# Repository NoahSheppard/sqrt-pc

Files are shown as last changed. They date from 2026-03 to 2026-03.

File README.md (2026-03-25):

## **UNDER CONSTRUCTION**

# Sqrt(PC)
A mini PC helper with a battery, and a microcontroller powerful enough to run programs itself...

For now this repo will be kept simple, with just the bare essentials in it. If you want a more in-depth guide into my inner thought process and how things came together over time, and feel that the commit history is weak, please find the Blueprint link [here](https://blueprint.hackclub.com/projects/13283)

# Bill Of Materials
<!-- BOM_START -->
| Reference | Qty | Value | Footprint | Price ($AUD unless marked) | Purchase-URL | Label | Notes |
| --- | --- | --- | --- | --- | --- | --- | --- |
| C46 | 1 | 100nF | C315C104K5R5TA:CAPRR254W54L381T254H466B | $0.70 | https://au.mouser.com/ProductDetail/KEMET/C315C104K5R5TA?qs=AHmto%252BvZ7OG2Mx7li%2Fn8YQ%3D%3D | Power Circuit - 100nF Capacitor |  |
| D1 | D2 | D3 | D5 | D6 | D7 | 6 | ~ | ScottoKeebs_Components:Diode_DO-35 | $- | N/A | Diodes for the Keyswitch array |  |
| D4 | 1 | LED_ARBG | LED_SMD:LED_Kingbright_AAA3528ESGCT | $0.74 | https://au.mouser.com/ProductDetail/Kingbright/AAA3528ESGCT?qs=HXFqYaX1Q2ztii0bK20PQg%3D%3D | LED for battery status |  |
| D9 | D10 | D11 | D12 | D13 | D14 | 6 | LED_SK6812MINI | ScottoKeebs_Components:LED_SK6812MINI | $- | N/A | RGB LEDs |  |
| DS1 | 1 | 4311 | 4311:MODULE_4311 | $9.37 | https://www.aliexpress.com/item/1005009447193931.html | Screen |  |
| J1 | 1 | Conn_01x02 | Connector_Molex:Molex_PicoBlade_53048-0210_1x02_P1.25mm_Horizontal | $3.76 | https://www.aliexpress.com/item/32807183020.html | Battery Connector | Can only get 50 min |
| Q1 | 1 | AO3401A | Package_TO_SOT_SMD:SOT-23W_Handsoldering | $0.97 | https://www.aliexpress.com/item/1005008934110148.html | Power Circuit - P-Channel MOSFET - Power Latch | Can only get 10 min |
| R2 | 1 | FMP100JR-52-2K2 | KiCADv6:FMP100JR_52_2K2 | $0.19 | https://au.mouser.com/ProductDetail/YAGEO/FMP100JR-52-2K2?qs=wcZjbqjoJegNfVYDP1qQwg%3D%3D | Power Circuit - 2.2kOhm Resistor |  |
| R3 | R4 | 2 | MFR-25FBF52-1K | MFR-25FBF52-1K:RESAD1100W55L680D260 | $0.31 | https://au.mouser.com/ProductDetail/YAGEO/MFR-25FTF52-1K47?qs=gt1LBUVyoHl4e3xmkemLyA%3D%3D | Power Circuit - 1.47 kOhms Resistor |  |
| R5 | R6 | 2 | RNC55H1002FMRE7 | RNC55H1002FMRE7:RESAD1081W64L635D269 | $0.85 | https://www.jaycar.com.au/10k-ohm-0-5-watt-metal-film-resistors-pack-of-8/p/RR0596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 | Power Circuit - 10kOhm Resistor | Can only get in a 8 pack for this cheap |
| RN1 | 1 | CAY16-1003F4LF | CAY16-1003F4LF:RESCAF80P320X160X60-8N | $0.15 | https://au.mouser.com/ProductDetail/Bourns/CAY16-1003F4LF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 | Power Circuit - 4 100kOhm Resistors |  |
| S1 | S2 | S3 | S5 | S6 | S7 | 6 | ~ | Button_Switch_Keyboard:SW_Cherry_MX_1.00u_PCB | $- | N/A | Keyswitches | I own these already |
| S8 | 1 | PTS526_SMG15_SMTR2_LFS | PTS526_SMG15_SMTR2_LFS:SW_PTS526_SMG15_SMTR2_LFS | $0.24 | https://au.mouser.com/ProductDetail/CK/PTS526SMG15SMTR2-LFS?qs=Imq1NPwxi76tu1Vo5JUXUg%3D%3D | Power Button |  |
| U1 | 1 | WEMOSC3mini | RF_Module:WEMOS_C3_mini | $8.94 | https://www.aliexpress.com/item/1005004740051202.html | Microcontroller | Does not come with pin headers |
| U2 | 1 | TP4056-42-ESOP8 | Package_SO:SOIC-8-1EP_3.9x4.9mm_P1.27mm_EP2.41x3.3mm | $1.44 | https://www.lcsc.com/product-detail/C16581.html | Power Circuit - IC | Price in AUD | purchased in USD - rough conversion rate |
|  | 2 |  |  | $0.35 | https://core-electronics.com.au/header-male-pin-01x20.html | Microcontroller Pin Headers | Not in KiCad |
|  |  |  |  |  |  |  |  |
| Total Price | $28.01 |  |  |  |  |  |  |
|  |  |  |  |  |  |  |  |
<!-- BOM_END -->

# Schematic
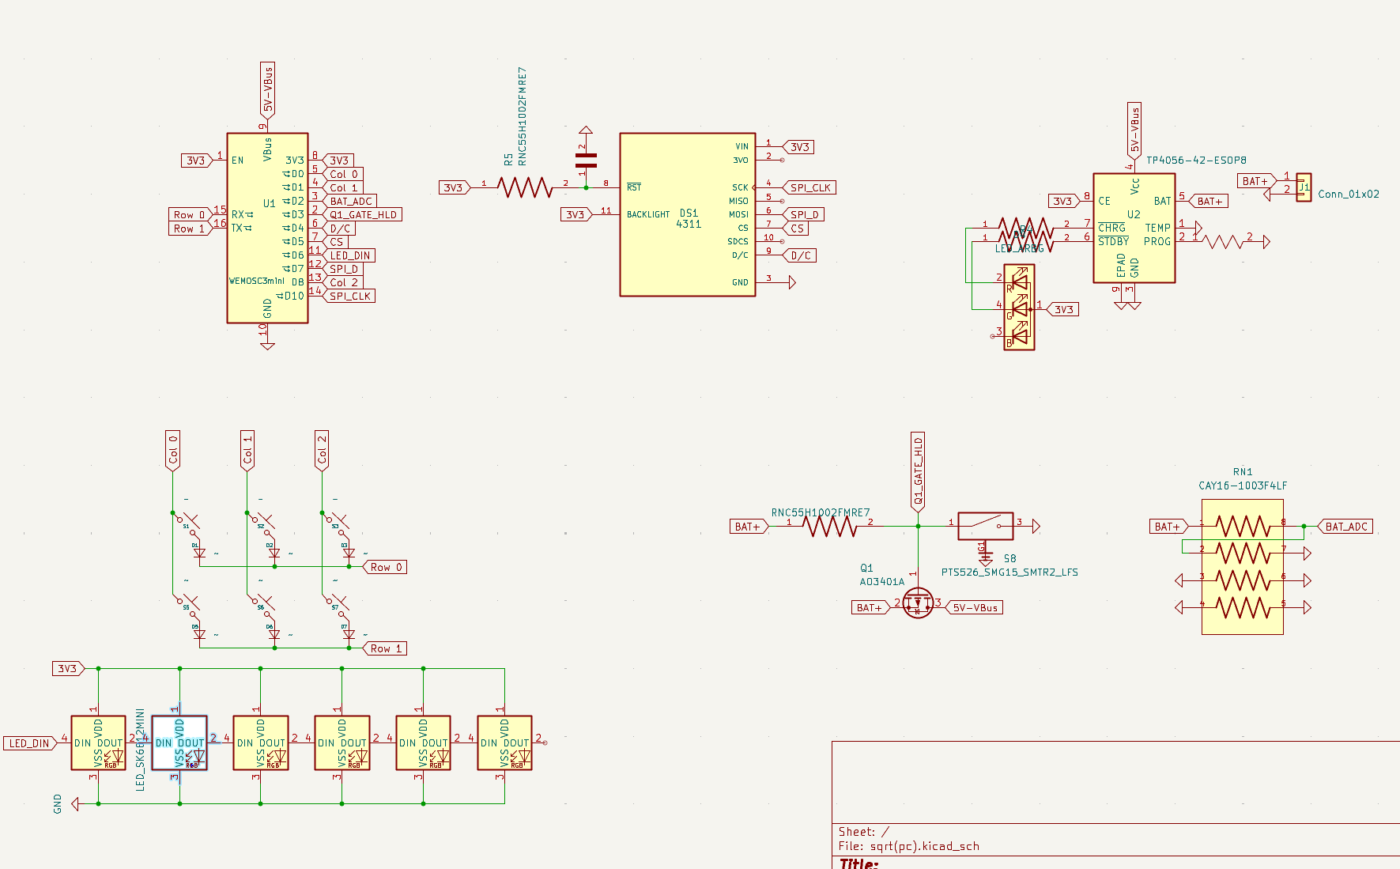
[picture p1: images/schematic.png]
Schematic


# PCB
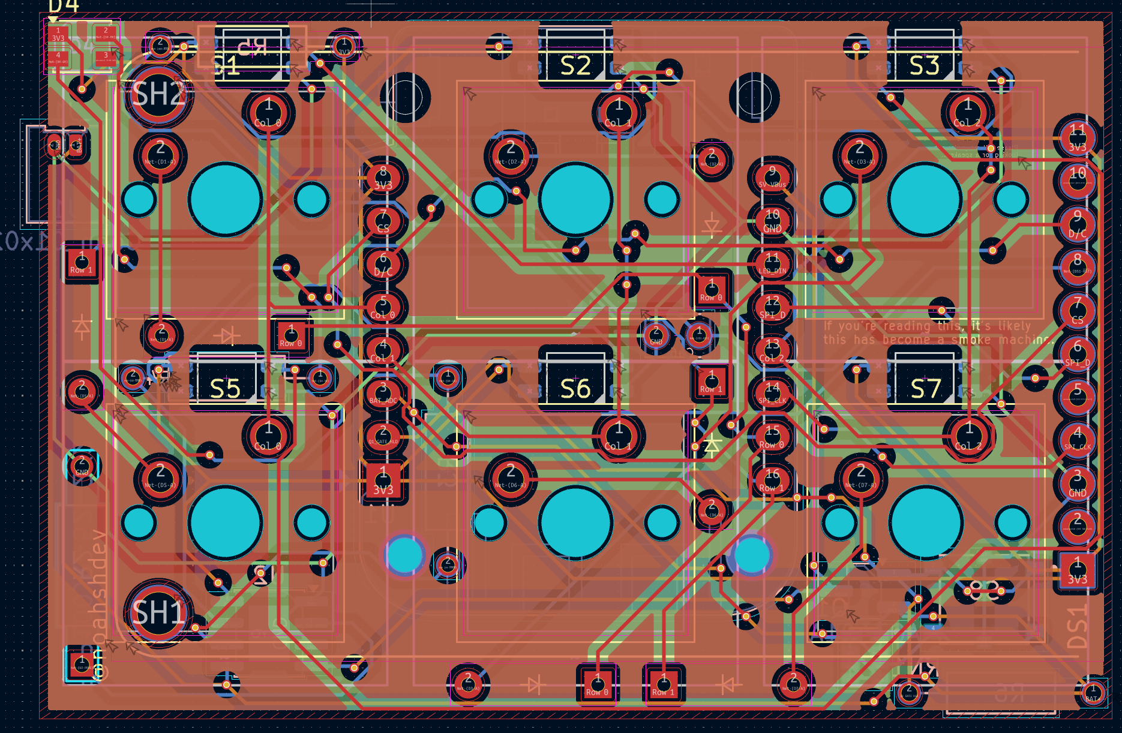
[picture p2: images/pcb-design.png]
PCB Design

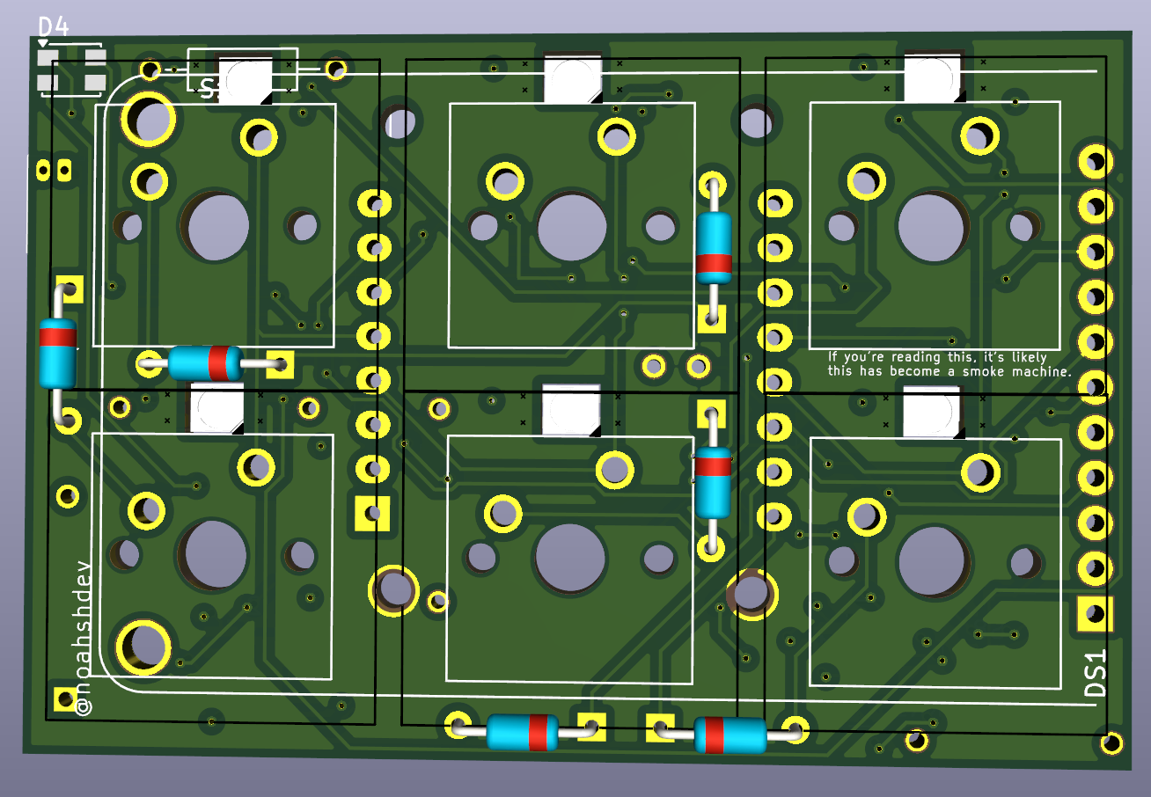
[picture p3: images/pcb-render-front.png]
PCB Render Front

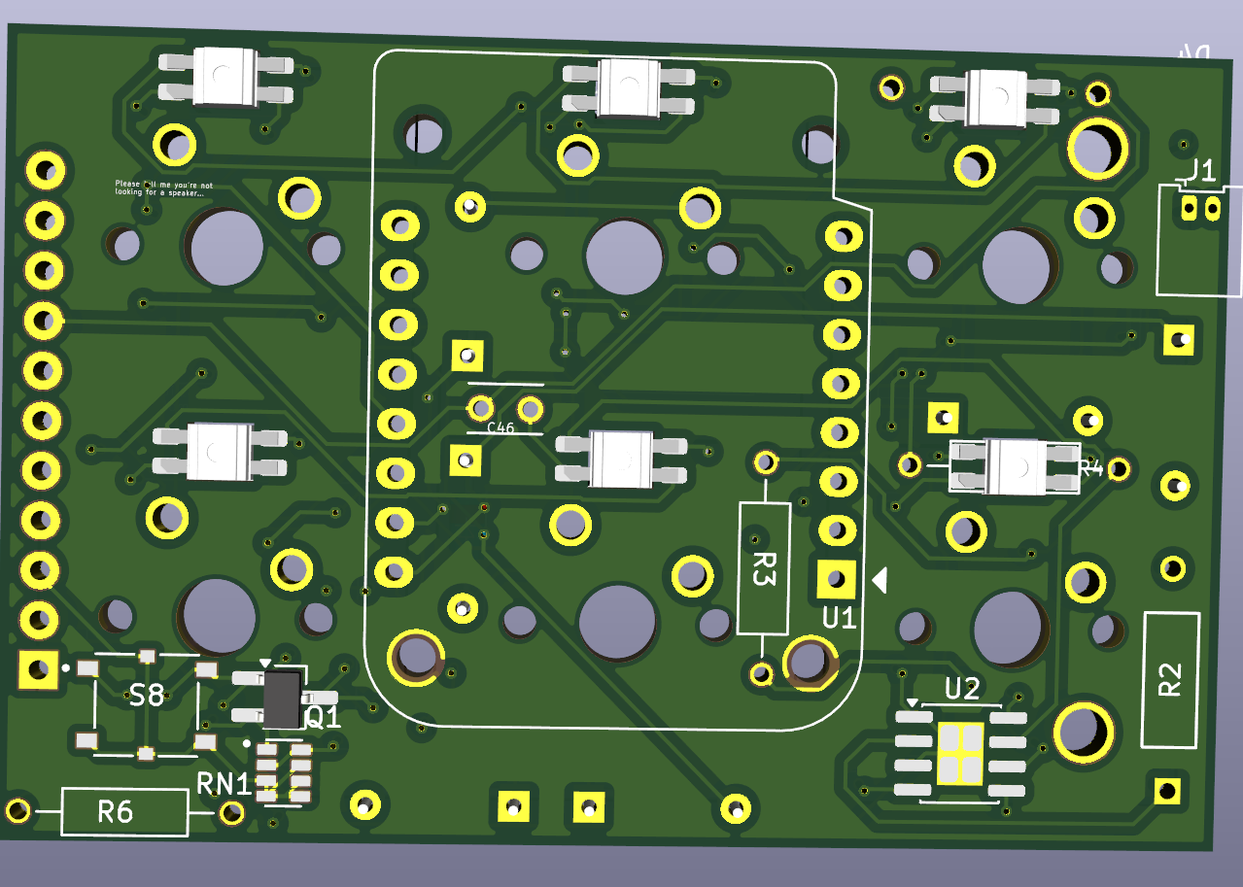
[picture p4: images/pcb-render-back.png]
PCB Render Back


# CAD
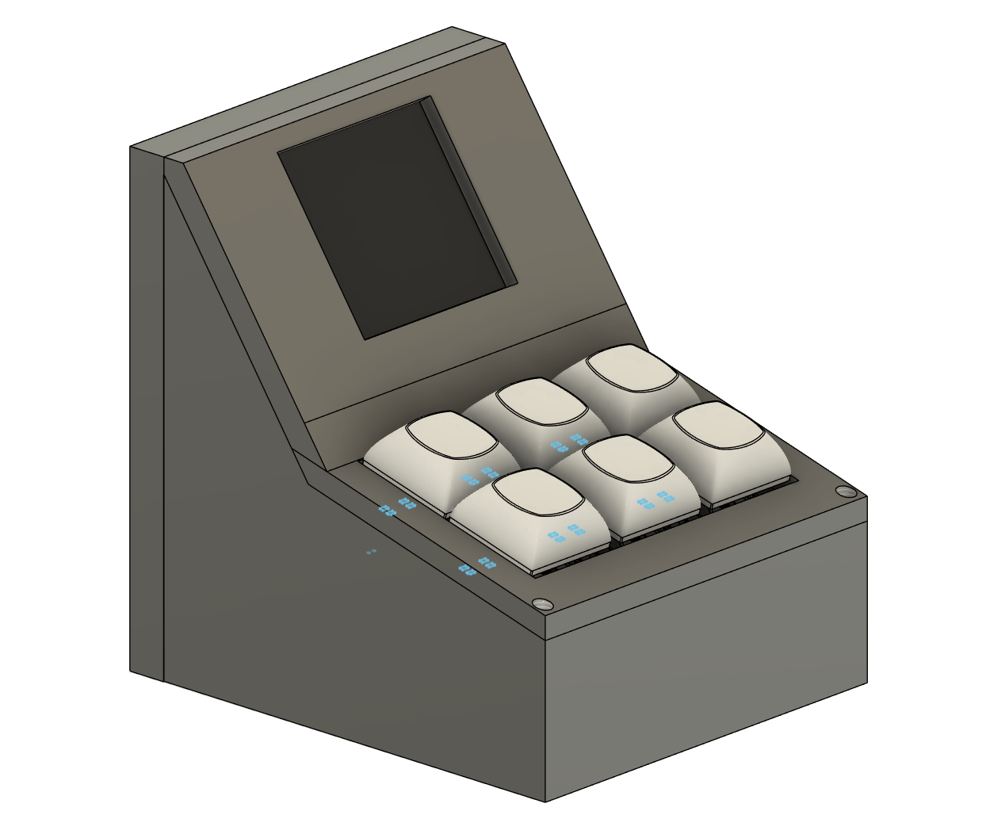
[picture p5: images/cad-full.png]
Full CAD Render

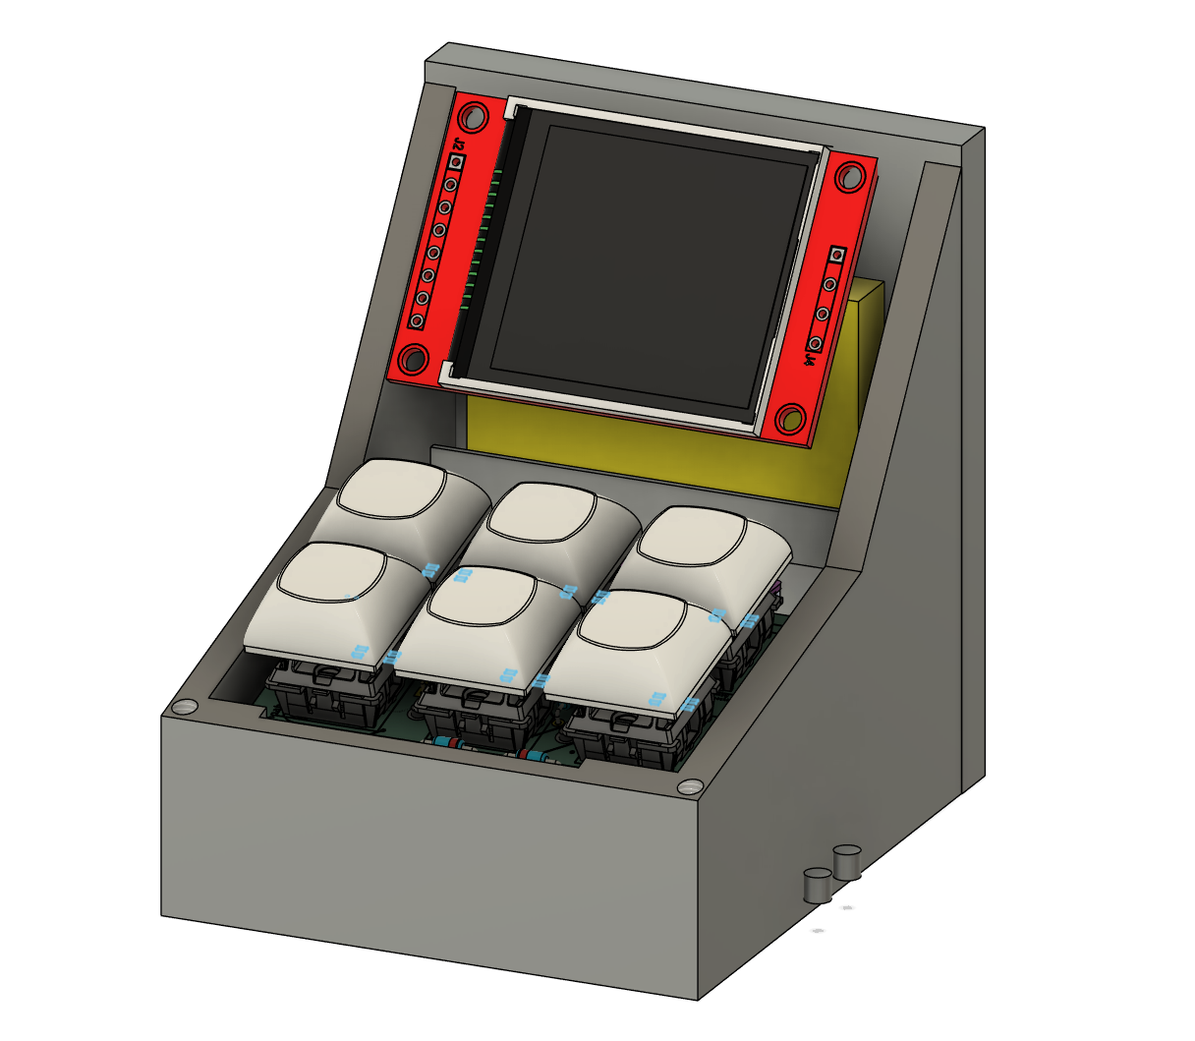
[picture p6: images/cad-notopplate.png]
CAD - No Top Plate

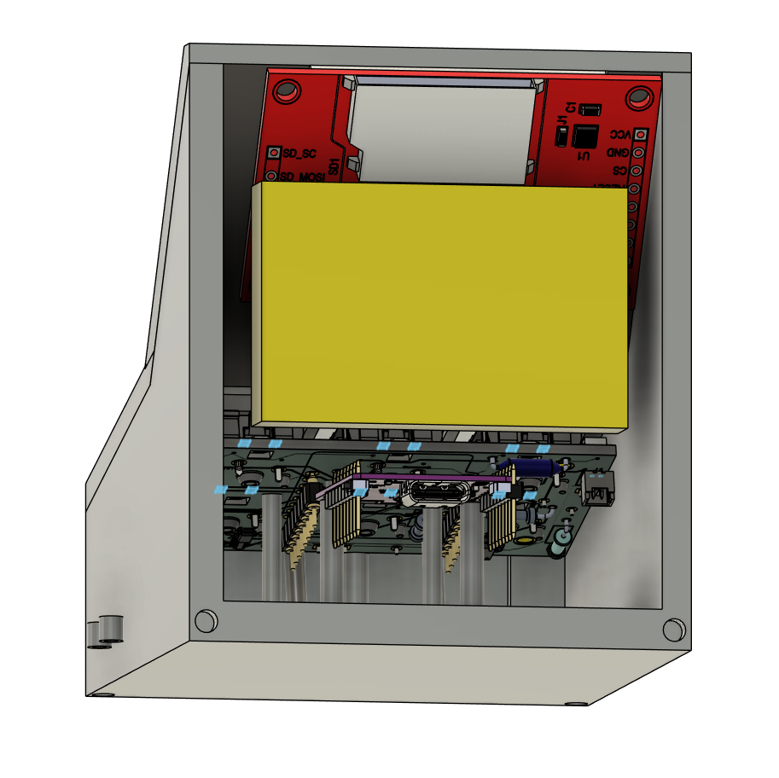
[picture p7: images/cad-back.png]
CAD - No Back Plate


# Firmware
tbd

## Disclaimer
AI was used in this project, to sanity check and to learn.

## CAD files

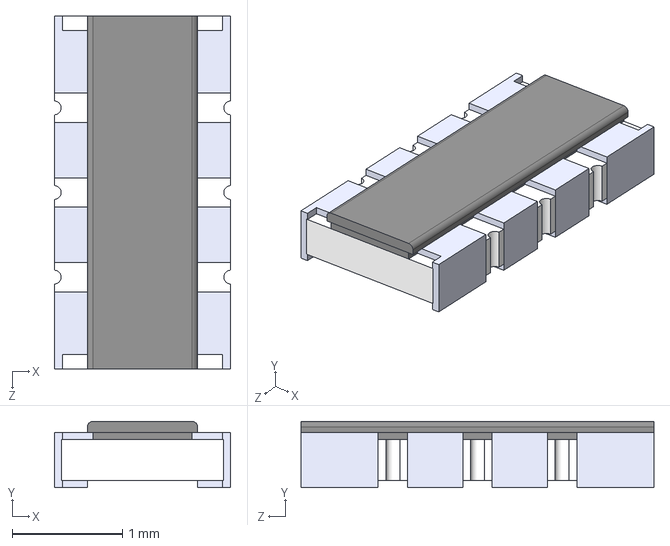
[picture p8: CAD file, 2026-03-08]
kicad_libraries/CAY16-1003F4LF/CAY16-1003F4LF.step
1.60 x 0.6 x 3.20 mm

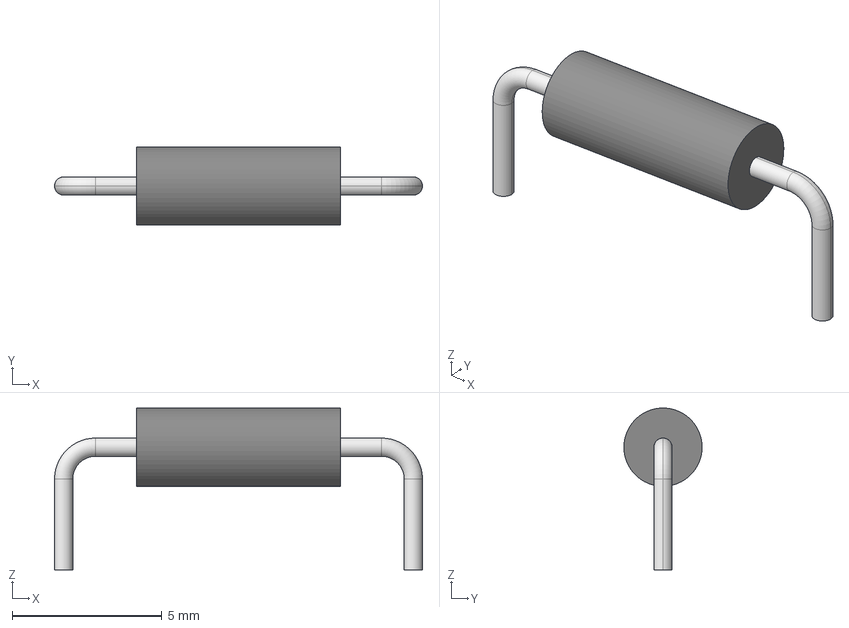
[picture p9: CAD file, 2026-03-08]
kicad_libraries/FMP100JR_52_2K2/YAG_FMP100_YAG.step
12.3 x 2.61 x 5.41 mm

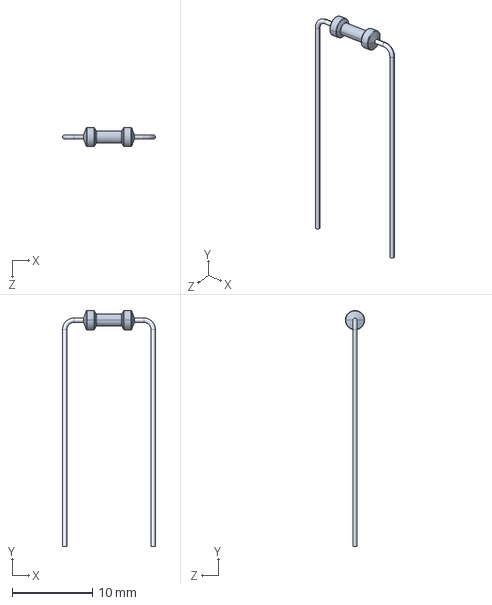
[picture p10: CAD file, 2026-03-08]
kicad_libraries/MFR-25FBF52-1K/MFR-25FBF52-1K.step
11.5 x 29.4 x 2.40 mm

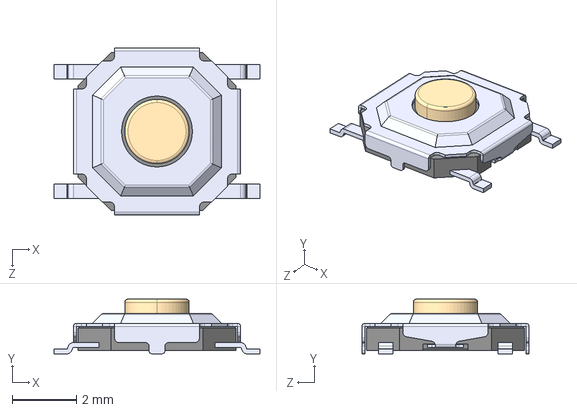
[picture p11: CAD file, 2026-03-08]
kicad_libraries/PTS526_SMG15_SMTR2_LFS/PTS526_SMG15_SMTR2_LFS.step
6.40 x 1.70 x 5.20 mm

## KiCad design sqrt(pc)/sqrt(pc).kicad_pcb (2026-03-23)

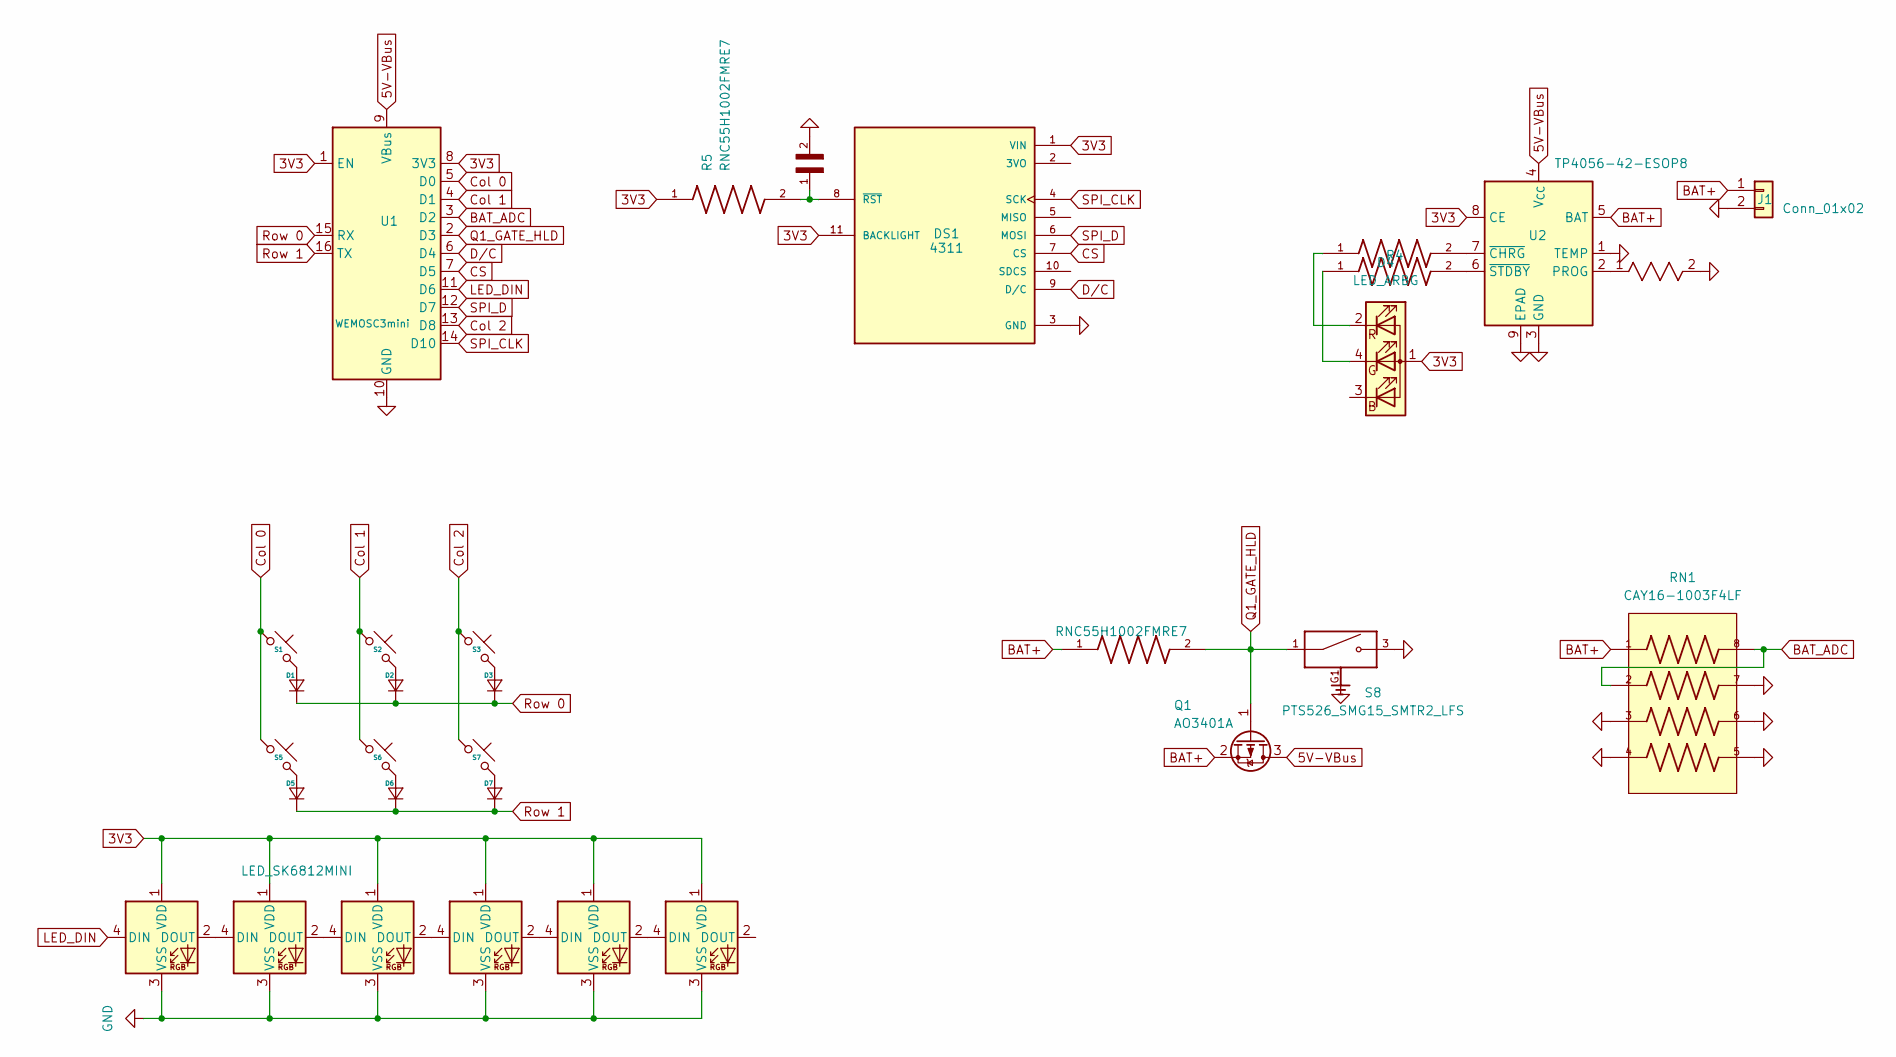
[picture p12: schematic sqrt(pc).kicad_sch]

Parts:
C46: 100nF; CAPRR254W54L381T254H466B; PARTREV 1/2/2025
D1, D2, D3, D5, D6, D7: Diode_DO-35
D4: LED_ARBG; LED_Kingbright_AAA3528ESGCT
D9, D10, D11, D12, D13, D14: LED_SK6812MINI; LCSC C5149201
DS1: 4311; MODULE_4311; PARTREV 2023-07-05
J1: Conn_01x02; Molex_PicoBlade_53048-0210_1x02_P1.25mm_Horizontal
Q1: AO3401A; SOT-23W_Handsoldering
R2: FMP100JR-52-2K2; FMP100JR_52_2K2
R3, R4: MFR-25FBF52-1K; RESAD1100W55L680D260; PARTREV 201304
R5, R6: RNC55H1002FMRE7; RESAD1081W64L635D269; PARTREV 01-Jan-2022
RN1: CAY16-1003F4LF; RESCAF80P320X160X60-8N
S1, S2, S3, S5, S6, S7: SW_Cherry_MX_1.00u_PCB
S8: PTS526_SMG15_SMTR2_LFS; SW_PTS526_SMG15_SMTR2_LFS; PARTREV 20 Nov 20
U1: WEMOSC3mini; WEMOS_C3_mini
U2: TP4056-42-ESOP8; SOIC-8-1EP_3.9x4.9mm_P1.27mm_EP2.41x3.3mm

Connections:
3V3: D4.1 (A), D9.1 (VDD), D10.1 (VDD), D11.1 (VDD), D12.1 (VDD), D13.1 (VDD), D14.1 (VDD), DS1.1 (VIN), DS1.11 (BACKLIGHT), R5.1, U1.1 (EN), U1.8 (3V3), U2.8 (CE)
5V-VBus: Q1.3 (D), U1.9 (VBus), U2.4 (V_{CC})
BAT+: J1.1, Q1.2 (S), R6.1, RN1.1, U2.5 (BAT)
BAT_ADC: RN1.2, RN1.8, U1.3 (D2)
CS: DS1.7 (CS), U1.7 (D5)
Col 0: S1.1, S5.1, U1.5 (D0)
Col 1: S2.1, S6.1, U1.4 (D1)
Col 2: S3.1, S7.1, U1.13 (D8)
D/C: DS1.9 (D/C), U1.6 (D4)
GND: C46.2, D9.3 (VSS), D10.3 (VSS), D11.3 (VSS), D12.3 (VSS), D13.3 (VSS), D14.3 (VSS), DS1.3 (GND), J1.2, R2.2, RN1.3, RN1.4, RN1.5, RN1.6, RN1.7, S8.3, S8.4, S8.G1, S8.G2, U1.10 (GND), U2.1 (TEMP), U2.3 (GND), U2.9 (EPAD)
LED_DIN: D9.4 (DIN), U1.11 (D6)
unnamed: D1.2 (A), S1.2
unnamed: D2.2 (A), S2.2
unnamed: D3.2 (A), S3.2
unnamed: D4.4 (GK), R3.1
unnamed: D4.2 (RK), R4.1
unnamed: D5.2 (A), S5.2
unnamed: D6.2 (A), S6.2
unnamed: D7.2 (A), S7.2
unnamed: D9.2 (DOUT), D10.4 (DIN)
unnamed: D10.2 (DOUT), D11.4 (DIN)
unnamed: D11.2 (DOUT), D12.4 (DIN)
unnamed: D12.2 (DOUT), D13.4 (DIN)
unnamed: D13.2 (DOUT), D14.4 (DIN)
unnamed: C46.1, DS1.8 (~RST), R5.2
unnamed: R2.1, U2.2 (PROG)
unnamed: R4.2, U2.7 (~CHRG)
unnamed: R3.2, U2.6 (~STDBY)
Q1_GATE_HLD: Q1.1 (G), R6.2, S8.1, S8.2, U1.2 (D3)
Row 0: D1.1 (K), D2.1 (K), D3.1 (K), U1.15 (RX)
Row 1: D5.1 (K), D6.1 (K), D7.1 (K), U1.16 (TX)
SPI_CLK: DS1.4 (SCK), U1.14 (D10)
SPI_D: DS1.6 (MOSI), U1.12 (D7)

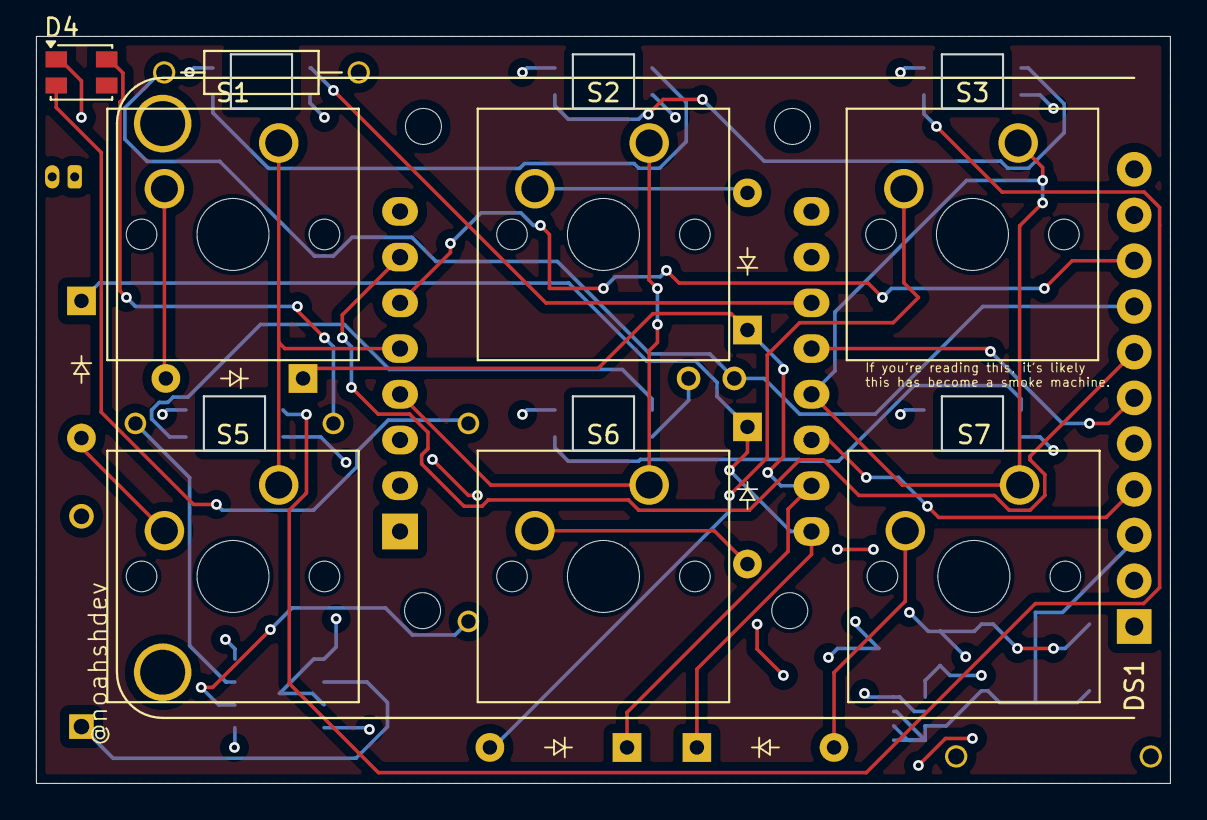
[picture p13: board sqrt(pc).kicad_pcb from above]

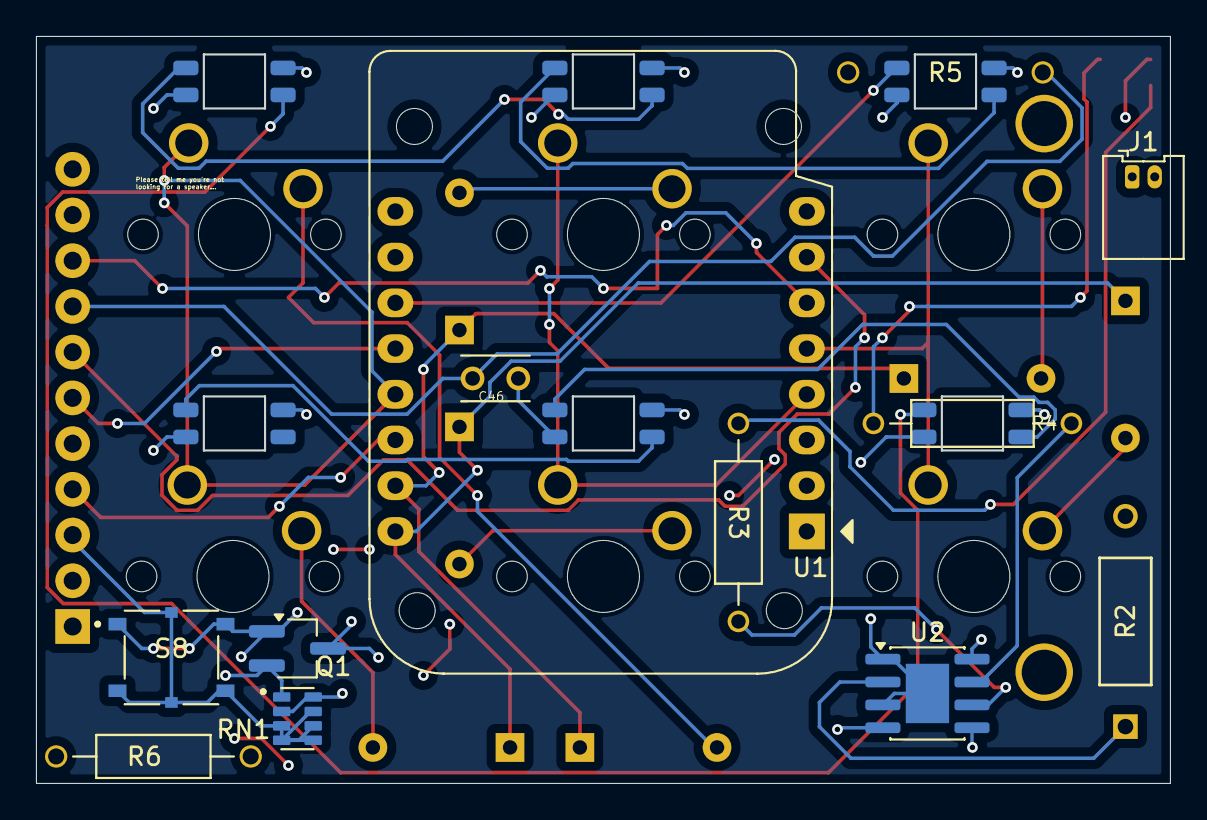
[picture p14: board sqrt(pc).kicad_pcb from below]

Board: 4 copper layers, 63.0 x 41.5 mm, 32 parts (17 on the bottom side), 33 nets.

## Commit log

2026-03-07 init commit
    [sqrt(pc).kicad_pcb, sqrt(pc).kicad_sch]
2026-03-08 finished wiring PCB
    [CAY16-1003F4LF.step, MFR-25FBF52-1K.step, PTS526_SMG15_SMTR2_LFS.step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]
2026-03-23 BOM + a lot more I guess
    [BOM.csv, BOM.xlsx, sqrt(pc).kicad_pcb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]
2026-03-25 more images + bom
2026-03-25 try and fix bom reference in readme file
2026-03-25 script to hopeuflly embed bom in readme
2026-03-25 testing script
    [BOM.csv]
2026-03-25 chore: update BOM table from CSV
